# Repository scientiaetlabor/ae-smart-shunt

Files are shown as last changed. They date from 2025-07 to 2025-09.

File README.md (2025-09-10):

<h1 align="center">
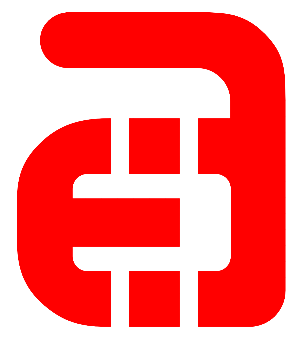
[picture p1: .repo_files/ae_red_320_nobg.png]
Ace's Electronics
    

  Ace's Electronics Pty Ltd  
  Smart Battery Shunt
</h1>

# Looking to get up and running?
- [Wiki - Quickstart Guide](../../wiki/Quickstart-Guide)

# Project Goals:
The overall goal of this project is to make a simple, robust and reliable Ssmart batery shunt to monitor voltage, current and power of a lithium battery, or battery system.

# Design goals:  
- Smallest form-factor possible while being able to handle large currents, upwards of 300A, without getting too hot
- Zero maintenance
- Allow the data to be accessed from an OLED gauge, via BLE or ESPNow

# Features
- **High-Precision Monitoring**: Measures battery voltage, current, and power, and calculates state-of-charge (SOC).
- **Persistent State**: Remembers battery capacity and calibration settings across power cycles.
- **ESP-NOW Broadcasting**: Transmits battery data wirelessly to other ESP devices.
- **Heartbeat LED**: A blinking LED provides a visual indication that the device is running.
- **Load Disconnect Control**: Includes an onboard MOSFET driver to disconnect the load in case of a fault.
- **Comprehensive Protection Suite**:
    - **Low-Voltage Disconnect**: Protects the battery from over-discharge. The device enters a low-power sleep mode, periodically waking to check if the battery has been recharged.
    - **Overcurrent Protection**: Disconnects the load if the current exceeds a configurable threshold.
    - **Short-Circuit Protection**: Uses the INA226's hardware alert pin for a fast-acting response to short circuits.
- **User-Configurable**: All protection parameters can be configured via the serial CLI.
- **In-Situ Calibration & Testing**: A guided CLI allows for accurate calibration and hardware verification without needing to re-flash the firmware.

# Commissioning
Before its first use, the smart shunt **must be calibrated**. The device will not be fully operational until this step is complete.
1.  Connect the device to a computer via USB.
2.  Open a serial monitor (e.g., the PlatformIO Serial Monitor) at **115200 baud**.
3.  Follow the on-screen prompts to run the calibration routines. You will be prompted to run the **Shunt Resistance Calibration (`r`)** first.
4.  Once calibration is complete, the device is ready for use.

# Serial Command-Line Interface (CLI)
The smart shunt is configured via a simple serial command-line interface. When connected, you can press a key followed by Enter to activate a command.

| Key | Command | Description |
|:---:|---|---|
| `c` | **Current Calibration** | Runs the guided multi-point current calibration routine. This maps the sensor's raw readings to true current values. |
| `r` | **Shunt Resistance Calibration** | Runs a routine to calculate the precise resistance of your shunt. **This must be run before first use.** |
| `p` | **Protection Settings** | Allows you to configure the thresholds for Low-Voltage Cutoff, Hysteresis, and Overcurrent Protection. |
| `l` | **Load Toggle** | Manually toggles the load disconnect MOSFET ON or OFF. Useful for testing the hardware circuit. |
| `a` | **Alert Toggle** | Toggles the hardware overcurrent alert ON or OFF. Useful for debugging. |
| `s` | **Status Display** | Displays the current protection settings, including the actual hardware alert threshold read from the INA226. |
| `d` | **Register Dump** | Prints the raw values of the INA226's key hardware registers for deep debugging. |

# v0.0.1
Version 0.0.1 has been prototyped. I will hand assemble some test boards and do some testing. ~ETA for completion is 10/8/25.

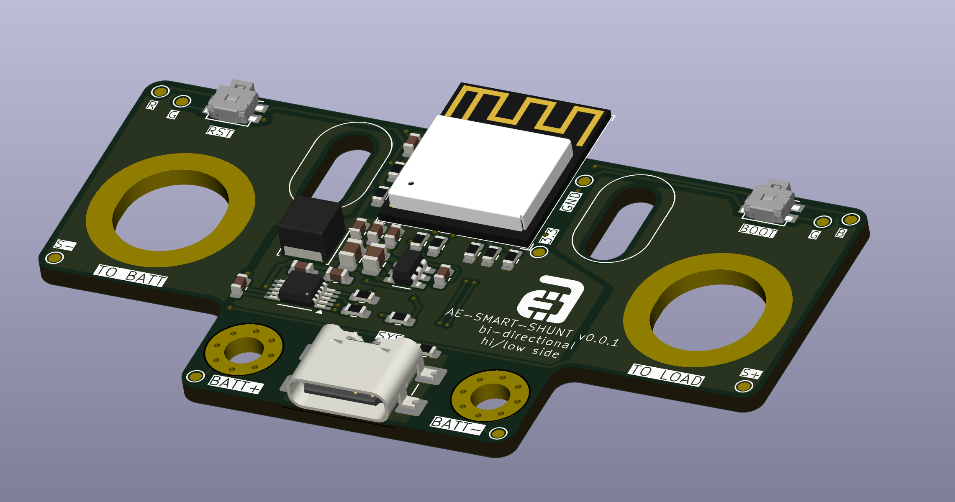
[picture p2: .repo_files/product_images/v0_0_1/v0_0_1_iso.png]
v0.0.1 PCB iso render

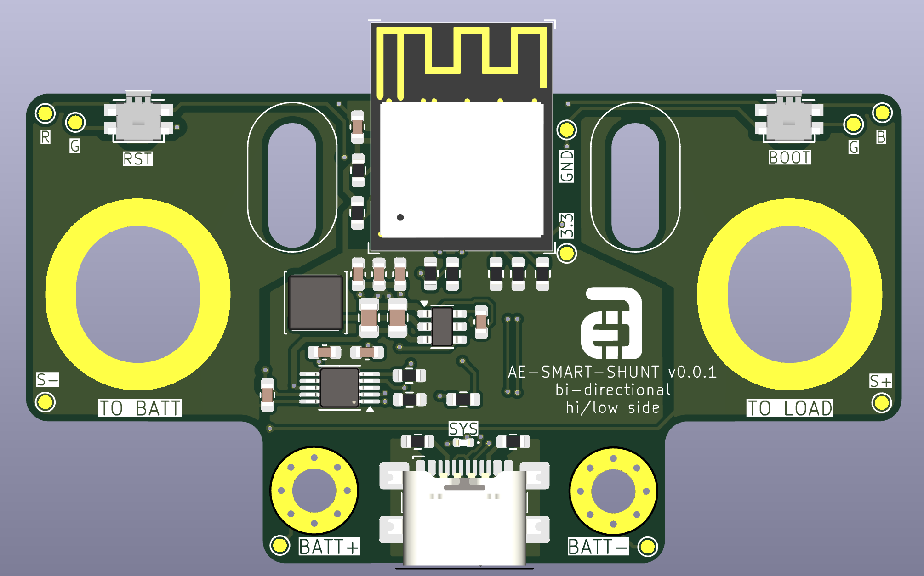
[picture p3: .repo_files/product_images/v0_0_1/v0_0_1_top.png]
v0.0.1 PCB top render

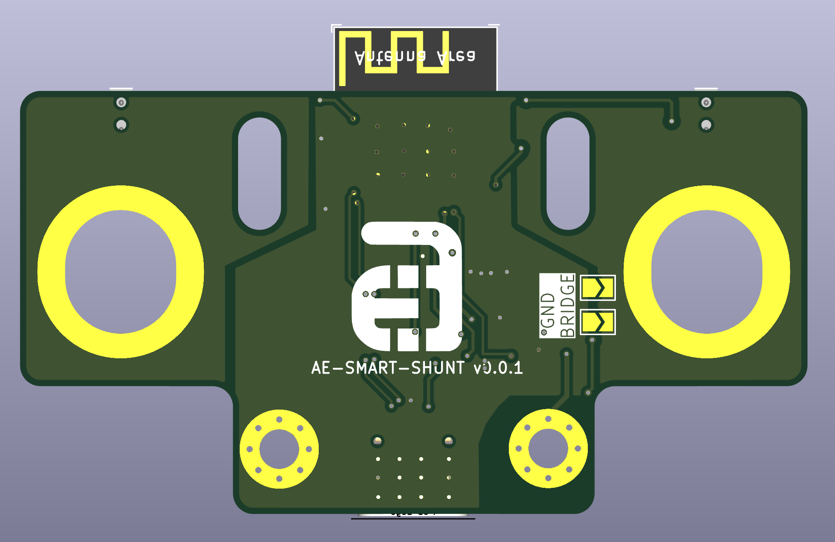
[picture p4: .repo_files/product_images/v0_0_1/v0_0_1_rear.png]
v0.0.1 PCB rear render

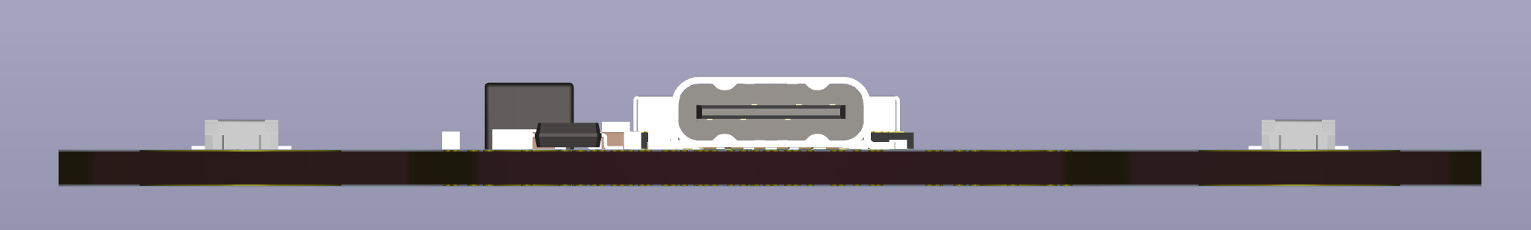
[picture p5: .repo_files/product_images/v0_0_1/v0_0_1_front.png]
v0.0.1 PCB front render


# Where to Buy:
TBA, but most likely will be vvailable to purchase in Australia or New Zealand via <a href="https://d1b959-f7.myshopify.com/">The AE Store</a>

## Support:
Contact me direct via ace<@>aceselectronics.com.au, just make it look like a normal email address. (hiding from the bots ;)

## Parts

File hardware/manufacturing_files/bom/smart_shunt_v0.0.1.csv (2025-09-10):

Reference | Value | Footprint | DNP | MFR | MFR# | lcsc
C1,C4,C6 | 10uF | Capacitor_SMD:C_0603_1608Metric,Capacitor_SMD:C_0805_2012Metric |  | Samsung Electro-Mechanics,muRata | CL10A106KP8NNNC,GRM21BR6YA106KE43L | C162422,C19702
C2,C5,C7,C8,C11 | 100nF | Capacitor_SMD:C_0603_1608Metric |  | YAGEO | CC0603KRX7R9BB104 | C14663
C3,C9,C10 | 22uF | Capacitor_SMD:C_0603_1608Metric |  | Samsung Electro-Mechanics | CL21A226MAQNNNE | C45783
C12 | 220nF | Capacitor_SMD:C_0805_2012Metric |  | Samsung Electro-Mechanics | CL21B224KBFNNNE | C5378
C13 | 220uF 50V | Capacitor_SMD:CP_Elec_8x10.5 |  | Honor Elec | VP1H221M0810 | C4054388
D1 | Green_LED | LED_SMD:LED_0402_1005Metric |  | Yongyu Photoelectric | SZYY0402YG | C434449
D5 | 1N5819WS | Diode_SMD:D_SOD-323 |  | JSMSEMI | 1N5819WS S4 | C2927280
J1 | SHUNT + | ShuntToPCB:MountingHole_17mm | DNP
J2 | SHUNT - | ShuntToPCB:MountingHole_17mm | DNP
J3 | VIn | MountingHole:MountingHole_3.2mm_M3_Pad_Via | DNP
J4 | USB_C_Receptacle_USB2.0 | Connector_USB:USB_C_Receptacle_GCT_USB4110 |  | SHOU HAN | TYPE-C 16P QTWT | C5187472
J5 | GND | MountingHole:MountingHole_3.2mm_M3_Pad_Via | DNP
J6 | Load Out | ShuntToPCB:MountingHole_17mm | DNP
L1 | 3.3uH | Inductor_SMD:L_APV_ANR4030 |  | Sunlord | SWPA4030S3R3MT | C15269
Q1,Q2 | CMSL008N06 | CMSL008N06:CMSL008N06 |  | Cmos | CMSL008N06 | C22364968
R1,R5,R6,R7,R8,R12 | 10k | Resistor_SMD:R_0603_1608Metric |  | UNI-ROYAL | 0603WAF1002T5E | C25804
R2,R3,R4,R9,R10 | 5.1k | Resistor_SMD:R_0603_1608Metric |  | UNI-ROYAL | 0603WAF5101T5E | C23186
R11,R13 | 33.2k | Resistor_SMD:R_0603_1608Metric |  | TyoHM | RMC060333.2K1%N | C325687
R14 | 180k | Resistor_SMD:R_0603_1608Metric |  | YAGEO | RC0603FR-07180KL | C123419
SW1,SW2 | SW_Push | Acea:ALPSALPINE-SKSCLBE010_C115361 |  | ALPSALPINE | SKSCLBE010 | C115361
U1 | ESP32-C3-MINI-1 | PCM_Espressif:ESP32-C3-MINI-1 |  | ESPRESSIF | ESP32-C3-MINI-1-H4 | C2934569
U2 | LM74502H-Q1 | Package_TO_SOT_SMD:SOT-23-8 |  | Texas Instruments | TI LM74502HQDDFRQ1 | C5219203
U4 | INA226 | Package_SO:VSSOP-10_3x3mm_P0.5mm |  | Texas Instruments | INA226AIDGSR | C49851
U5 | TPS562201 | Package_TO_SOT_SMD:SOT-23-6 |  | Texas Instruments | TPS562201DDCR | C90061

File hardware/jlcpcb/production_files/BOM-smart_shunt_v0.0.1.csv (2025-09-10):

Comment | Designator | Footprint | LCSC | Quantity
SW_Push | SW1,SW2 | ALPSALPINE-SKSCLBE010_C115361 | C115361 | 2
180k | R14 | R_0603_1608Metric | C123419 | 1
100nF | C11,C2,C5,C7,C8 | C_0603_1608Metric | C14663 | 5
3.3uH | L1 | L_APV_ANR4030 | C15269 | 1
10uF | C4,C6 | C_0805_2012Metric | C15850 | 2
10uF | C1 | C_0603_1608Metric | C19702 | 1
CMSL008N06 | Q1,Q2 | CMSL008N06 | C22364968 | 2
5.1k | R10,R2,R3,R4,R9 | R_0603_1608Metric | C23186 | 5
10k | R1,R12,R5,R6,R7,R8 | R_0603_1608Metric | C25804 | 6
ESP32-C3-MINI-1 | U1 | ESP32-C3-MINI-1 | C2838502 | 1
1N5819WS | D5 | D_SOD-323 | C2927280 | 1
33.2k | R11,R13 | R_0603_1608Metric | C325687 | 2
Green_LED | D1 | LED_0402_1005Metric | C401111 | 1
220uF 50V | C13 | CP_Elec_8x10.5 | C4054388 | 1
INA226 | U4 | VSSOP-10_3x3mm_P0.5mm | C49851 | 1
USB_C_Receptacle_USB2.0 | J4 | USB_C_Receptacle_GCT_USB4110 | C5187472 | 1
LM74502H-Q1 | U2 | SOT-23-8 | C5219203 | 1
220nF | C12 | C_0805_2012Metric | C5378 | 1
22uF | C10,C3,C9 | C_0603_1608Metric | C59461 | 3
TPS562201 | U5 | SOT-23-6 | C90061 | 1
SHUNT + |  | MountingHole_17mm |  | 0
GND |  | MountingHole_3.2mm_M3_Pad_Via |  | 0
SHUNT - |  | MountingHole_17mm |  | 0
VIn |  | MountingHole_3.2mm_M3_Pad_Via |  | 0
Load Out |  | MountingHole_17mm |  | 0

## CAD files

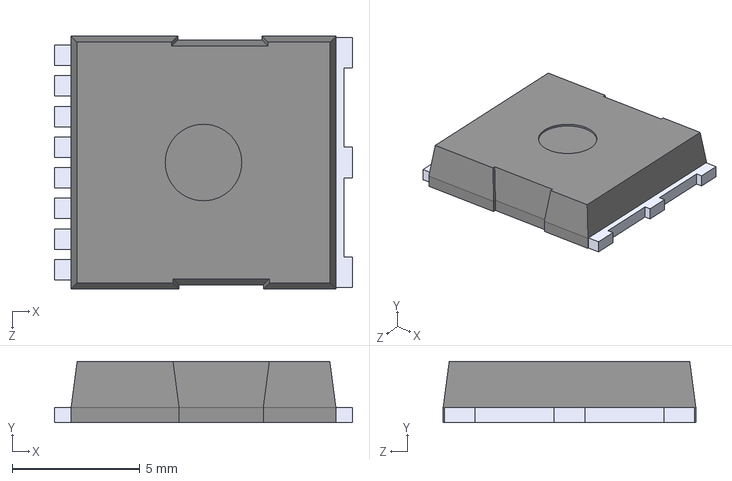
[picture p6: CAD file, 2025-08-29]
hardware/parts/CMSL008N06/CMSL008N06.step
11.7 x 2.40 x 9.90 mm

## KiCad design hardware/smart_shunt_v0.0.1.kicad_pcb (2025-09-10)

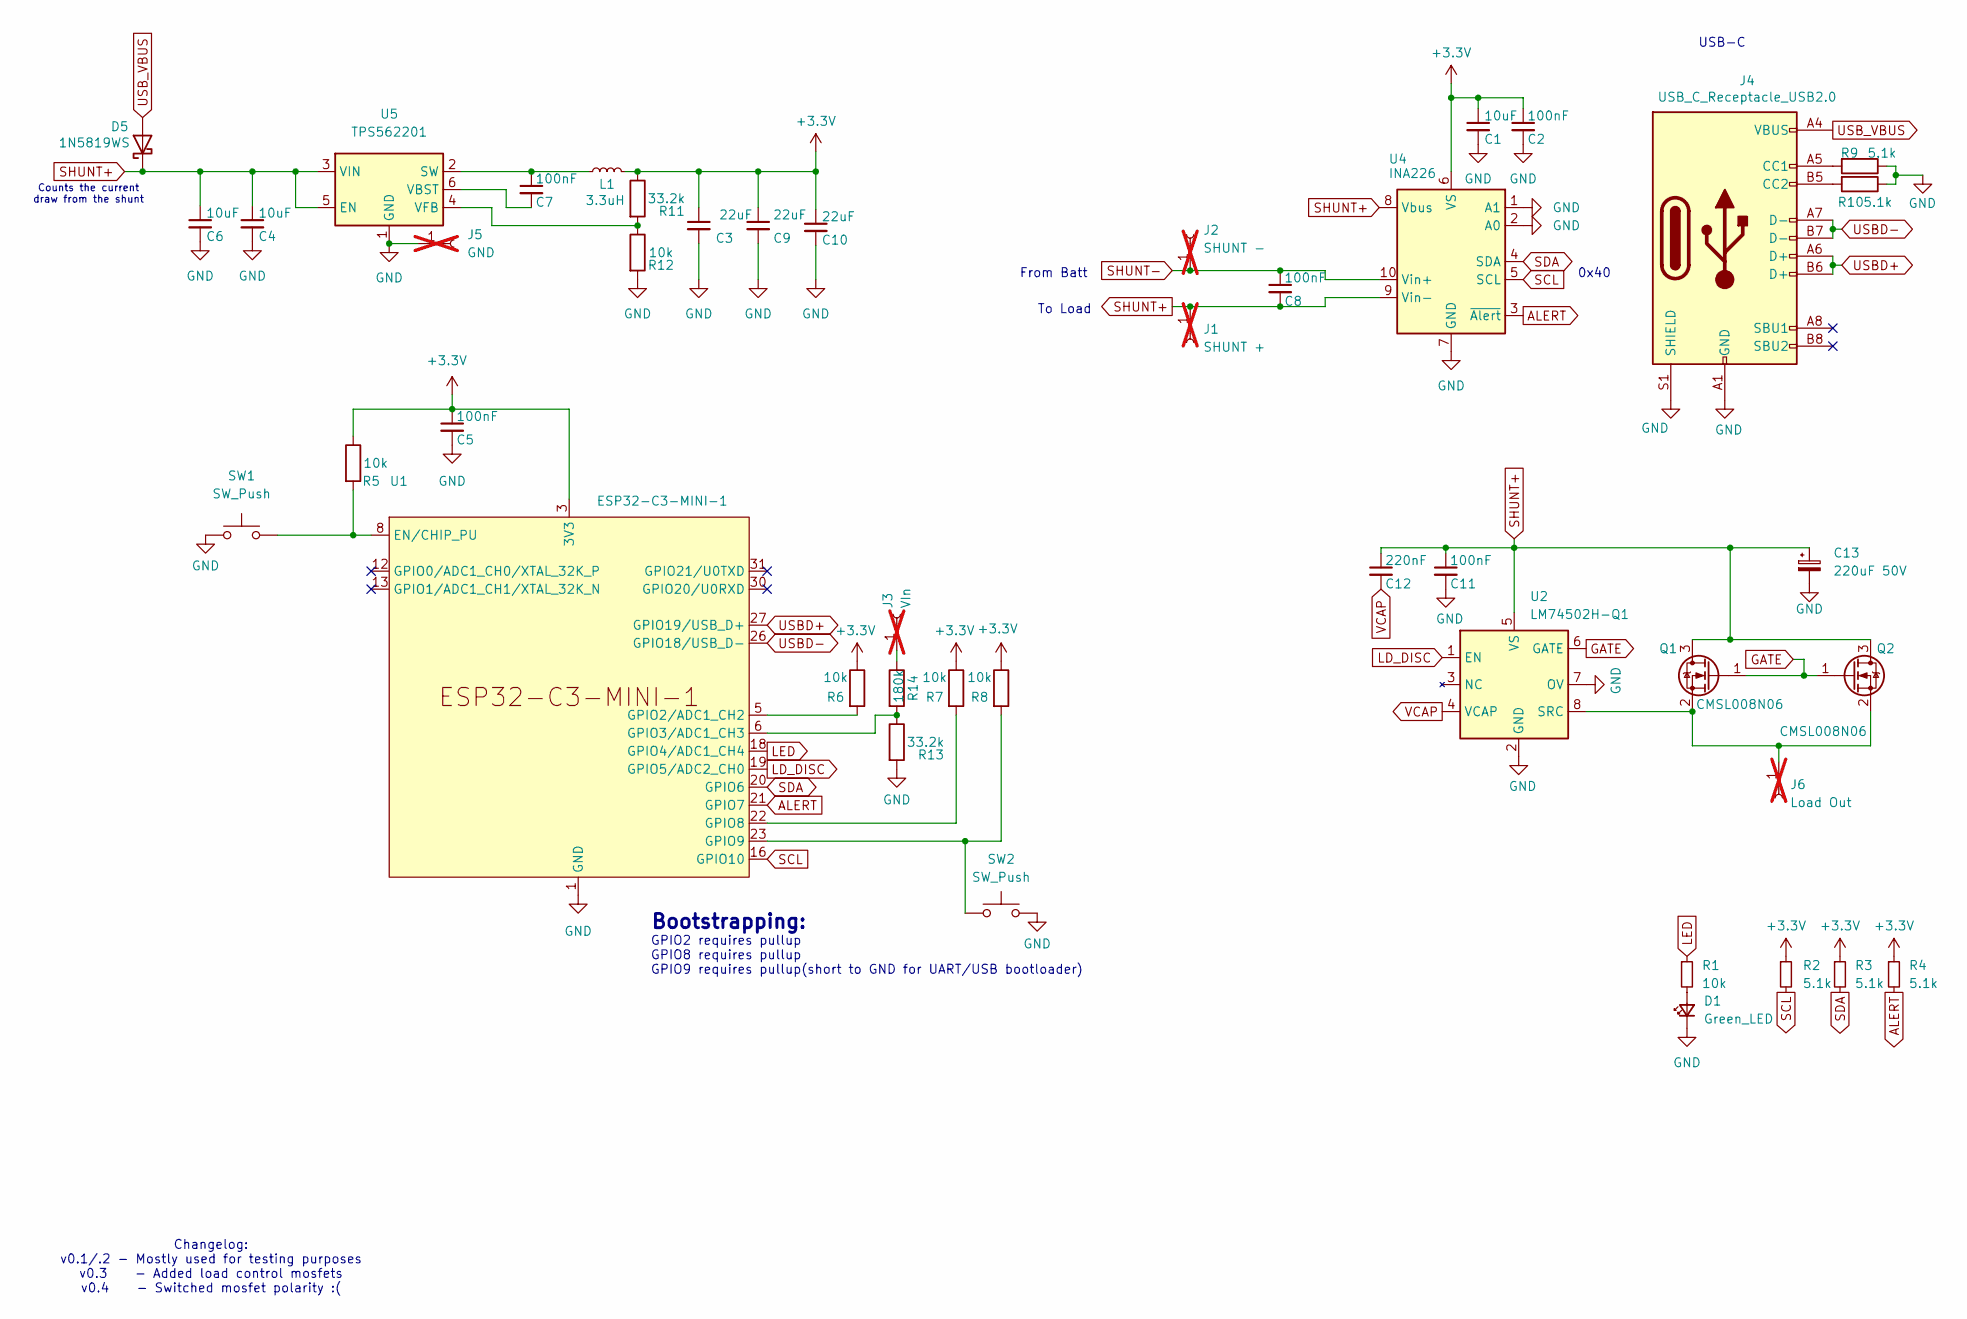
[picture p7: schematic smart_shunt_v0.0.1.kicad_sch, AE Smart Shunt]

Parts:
C1: 10uF; C_0603_1608Metric; MFR# CL10A106KP8NNNC; lcsc C19702
C2, C5, C7, C8, C11: 100nF; C_0603_1608Metric; MFR# CC0603KRX7R9BB104; lcsc C14663
C3, C9, C10: 22uF; C_0603_1608Metric; MFR# CL21A226MAQNNNE; lcsc C45783
C4, C6: 10uF; C_0805_2012Metric; MFR# GRM21BR6YA106KE43L; lcsc C162422
C12: 220nF; C_0805_2012Metric; MFR# CL21B224KBFNNNE; lcsc C5378
C13: 220uF 50V; CP_Elec_8x10.5; MFR# VP1H221M0810; lcsc C4054388
D1: Green_LED; LED_0402_1005Metric; MFR# SZYY0402YG; lcsc C434449
D5: 1N5819WS; D_SOD-323; MFR# 1N5819WS S4; lcsc C2927280
J1: SHUNT +; MountingHole_17mm; not fitted
J2: SHUNT -; MountingHole_17mm; not fitted
J3: VIn; MountingHole_3.2mm_M3_Pad_Via; not fitted
J4: USB_C_Receptacle_USB2.0; USB_C_Receptacle_GCT_USB4110; MFR# TYPE-C 16P QTWT; LCSC C5187472
J5: GND; MountingHole_3.2mm_M3_Pad_Via; not fitted
J6: Load Out; MountingHole_17mm; not fitted
L1: 3.3uH; L_APV_ANR4030; MFR# SWPA4030S3R3MT; lcsc C15269
Q1, Q2: CMSL008N06; MFR# CMSL008N06; lcsc C22364968
R1, R5, R6, R7, R8, R12: 10k; R_0603_1608Metric; MFR# 0603WAF1002T5E; lcsc C25804
R2, R3, R4, R9, R10: 5.1k; R_0603_1608Metric; MFR# 0603WAF5101T5E; lcsc C23186
R11, R13: 33.2k; R_0603_1608Metric; MFR# RMC060333.2K1%N; lcsc C325687
R14: 180k; R_0603_1608Metric; MFR# RC0603FR-07180KL; lcsc C123419
SW1, SW2: SW_Push; ALPSALPINE-SKSCLBE010_C115361; MFR# SKSCLBE010; lcsc C115361
U1: ESP32-C3-MINI-1; MFR# ESP32-C3-MINI-1-H4; lcsc C2934569
U2: LM74502H-Q1; SOT-23-8; MFR# TI LM74502HQDDFRQ1; lcsc C5219203
U4: INA226; VSSOP-10_3x3mm_P0.5mm; MFR# INA226AIDGSR; lcsc C49851
U5: TPS562201; SOT-23-6; MFR# TPS562201DDCR; lcsc C90061

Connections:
+3.3V: C1.1, C2.1, C3.1, C5.1, C9.1, C10.1, L1.2, R2.1, R3.1, R4.1, R5.1, R6.1, R7.1, R8.1, R11.1, U1.3 (3V3), U4.6 (VS)
ALERT: R4.2, U1.21 (GPIO7), U4.3 (~Alert)
GATE: Q1.1 (G), Q2.1 (G), U2.6 (GATE)
GND: C1.2, C2.2, C3.2, C4.2, C5.2, C6.2, C9.2, C10.2, C11.2, C13.2, D1.1 (K), J4.A1 (GND), J4.A12 (GND), J4.B1 (GND), J4.B12 (GND), J4.S1 (SHIELD), J5.1, R9.1, R10.1, R12.2, R13.2, SW1.2, SW2.2, U1.1 (GND), U1.2 (GND), U1.11 (GND), U1.14 (GND), U1.36 (GND), U1.37 (GND), U1.38 (GND), U1.39 (GND), U1.40 (GND), U1.41 (GND), U1.42 (GND), U1.43 (GND), U1.44 (GND), U1.45 (GND), U1.46 (GND), U1.47 (GND), U1.48 (GND), U1.49 (GND), U1.50 (GND), U1.51 (GND), U1.52 (GND), U1.53 (GND), U2.2 (GND), U2.7 (OV), U4.1 (A1), U4.2 (A0), U4.7 (GND), U5.1 (GND)
LD_DISC: U1.19 (GPIO5/ADC2_CH0), U2.1 (EN)
LED: R1.1, U1.18 (GPIO4/ADC1_CH4)
unnamed: D1.2 (A), R1.2
unnamed: J3.1, R14.1
unnamed: J4.A5 (CC1), R9.2
unnamed: J4.B5 (CC2), R10.2
unnamed: J6.1, Q1.2 (S), Q2.2 (S), U2.8 (SRC)
unnamed: R5.2, SW1.1, U1.8 (EN/CHIP_PU)
unnamed: R6.2, U1.5 (GPIO2/ADC1_CH2)
unnamed: R13.1, R14.2, U1.6 (GPIO3/ADC1_CH3)
unnamed: R7.2, U1.22 (GPIO8)
unnamed: R8.2, SW2.1, U1.23 (GPIO9)
unnamed: C7.1, L1.1, U5.2 (SW)
unnamed: C7.2, U5.6 (VBST)
unnamed: R11.2, R12.1, U5.4 (VFB)
SCL: R2.2, U1.16 (GPIO10), U4.5 (SCL)
SDA: R3.2, U1.20 (GPIO6), U4.4 (SDA)
SHUNT+: C4.1, C6.1, C8.2, C11.1, C12.1, C13.1, D5.1 (K), J1.1, Q1.3 (D), Q2.3 (D), U2.5 (VS), U4.8 (Vbus), U4.9 (Vin-), U5.3 (VIN), U5.5 (EN)
SHUNT-: C8.1, J2.1, U4.10 (Vin+)
USBD+: J4.A6 (D+), J4.B6 (D+), U1.27 (GPIO19/USB_D+)
USBD-: J4.A7 (D-), J4.B7 (D-), U1.26 (GPIO18/USB_D-)
USB_VBUS: D5.2 (A), J4.A4 (VBUS), J4.A9 (VBUS), J4.B4 (VBUS), J4.B9 (VBUS)
VCAP: C12.2, U2.4 (VCAP)

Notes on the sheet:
0x40
USB-C
From Batt
Counts the current draw from the shunt
Changelog: v0.1/.2 - Mostly used for testing purposes v0.3 - Added load control mosfets v0.4 - Switched mosfet polarity :(
To Load
Bootstrapping:
GPIO2 requires pullup GPIO8 requires pullup GPIO9 requires pullup(short to GND for UART/USB bootloader)

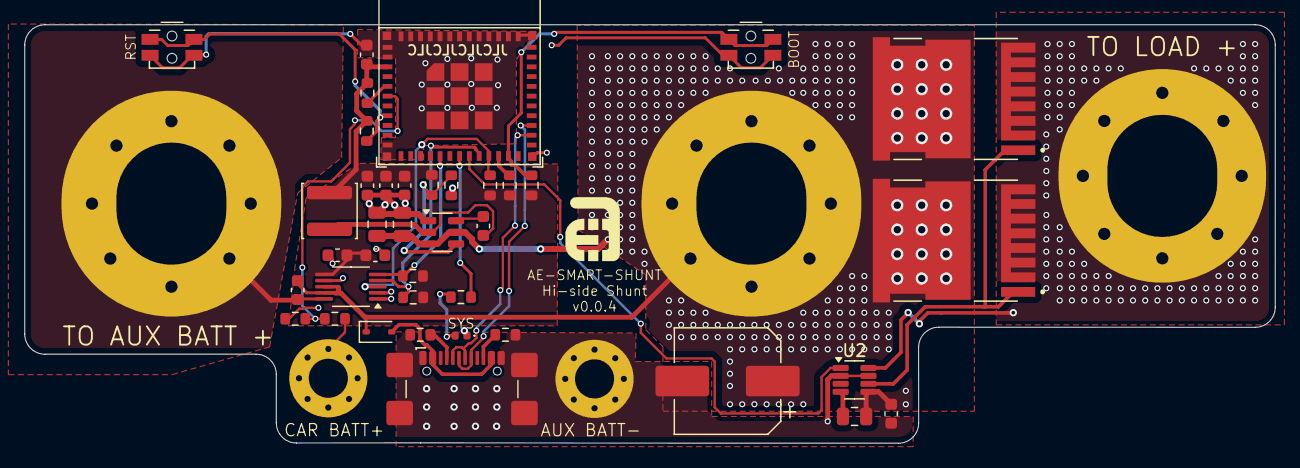
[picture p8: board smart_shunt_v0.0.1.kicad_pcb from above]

Board: 2 copper layers, 102.4 x 34.3 mm, 44 parts (0 on the bottom side), 27 nets.

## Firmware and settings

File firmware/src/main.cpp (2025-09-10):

#include <vector>
#include <Arduino.h>
#include <Preferences.h>
#include "shared_defs.h"
#include "ina226_adc.h"
#include "ble_handler.h"
#include "espnow_handler.h"
#include "passwords.h"
#include <esp_now.h>
#include <esp_err.h>

// WiFi and OTA
#include <WiFi.h>
#include <WiFiClientSecure.h>
#include <ota-github-cacerts.h>
#include <ota-github-defaults.h>
#define OTAGH_OWNER_NAME "Aces-Electronics"
#define OTAGH_REPO_NAME "ae-smart-shunt"
#include <OTA-Hub.hpp>

#define USE_ADC // if defined, use ADC, else, victron BLE
// #define USE_WIFI // if defined, conect to WIFI, else, don't

float batteryCapacity = 100.0f; // Default rated battery capacity in Ah (used for SOC calc)

uint8_t broadcastAddress[] = {0xFF, 0xFF, 0xFF, 0xFF, 0xFF, 0xFF};

// OTA update check interval (24 hours)
const unsigned long ota_check_interval = 24 * 60 * 60 * 1000;
unsigned long last_ota_check = 0;

// Main loop interval
const unsigned long loop_interval = 10000;
unsigned long last_loop_millis = 0;

// LED Heartbeat
unsigned long last_led_blink = 0;
const unsigned long led_blink_interval = 500; // ms

struct_message_ae_smart_shunt_1 ae_smart_shunt_struct;
// Initializing with a default shunt resistor value, which will be overwritten
// if a calibrated value is loaded from NVS.
INA226_ADC ina226_adc(I2C_ADDRESS, 0.000944464f, 100.00f);
ESPNowHandler espNowHandler(broadcastAddress); // ESP-NOW handler for sending data
WiFiClientSecure wifi_client;

void IRAM_ATTR alertISR() {
  ina226_adc.handleAlert();
}

bool handleOTA()
{
  // 1. Check for updates, by checking the latest release on GitHub
  OTA::UpdateObject details = OTA::isUpdateAvailable();

  if (OTA::NO_UPDATE == details.condition)
  {
    Serial.println("No new update available. Continuing...");
    return false;
  }
  else
  // 2. Perform the update (if there is one)
  {
    Serial.println("Update available, saving battery capacity...");
    Preferences preferences;
    preferences.begin("storage", false);
    float capacity = ina226_adc.getBatteryCapacity();
    preferences.putFloat("bat_cap", capacity);
    preferences.end();
    Serial.printf("Saved battery capacity: %f\n", capacity);

    if (OTA::performUpdate(&details) == OTA::SUCCESS)
    {
      // .. success! It'll restart by default, or you can do other things here...
      return true;
    }
  }
  return false;
}

void daily_ota_check()
{
  if (millis() - last_ota_check > ota_check_interval)
  {
    // Notify the user that we are checking for updates
    strncpy(ae_smart_shunt_struct.runFlatTime, "Checking for updates...", sizeof(ae_smart_shunt_struct.runFlatTime));
    espNowHandler.setAeSmartShuntStruct(ae_smart_shunt_struct);
    espNowHandler.sendMessageAeSmartShunt();
    delay(100); // Give a moment for the message to be sent

    // Stop ESP-NOW to allow WiFi to connect
    esp_now_deinit();

    // WiFi connection
    WiFi.begin(WIFI_SSID, WIFI_PASS);
    Serial.print("Connecting to WiFi for OTA check");
    while (WiFi.status() != WL_CONNECTED)
    {
      Serial.print(".");
      delay(500);
    }
    Serial.println("\nConnected to WiFi");

    bool updated = handleOTA();
    last_ota_check = millis();

    WiFi.disconnect(true);
    WiFi.mode(WIFI_OFF);
    Serial.println("WiFi disconnected");

    if (!updated)
    {
      // Re-initialize ESP-NOW
      if (!espNowHandler.begin())
      {
        Serial.println("ESP-NOW init failed after OTA check");
      }
    }
  }
}

// helper: read a trimmed line from Serial (blocks until newline)
static String SerialReadLineBlocking()
{
  String s;
  while (true)
  {
    while (Serial.available() == 0)
      delay(5);
    s = Serial.readStringUntil('\n');
    s.trim();
    if (s.length() > 0)
      return s;
    // allow empty Enter to be treated as empty string
    return s;
  }
}

// Helper: wait for enter or 'x' while optionally streaming debug raw vs calibrated values.
// Returns the user-entered line (possibly empty string if they just pressed Enter), or "x" if canceled.
static String waitForEnterOrXWithDebug(INA226_ADC &ina, bool debugMode)
{
  // Flush any existing chars
  while (Serial.available())
    Serial.read();

  unsigned long lastPrint = 0;
  const unsigned long printInterval = 300; // ms

  while (true)
  {
    if (Serial.available())
    {
      String line = Serial.readStringUntil('\n');
      line.trim();
      if (line.length() == 0)
      {
        // Enter pressed (empty line) - record step
        return String("");
      }
      else
      {
        // Could be 'x' or other input
        if (line.equalsIgnoreCase("x"))
          return String("x");
        // treat any non-empty as confirmation as well
        return line;
      }
    }

    // Periodically print debug readings if enabled
    unsigned long now = millis();
    if (debugMode && (now - lastPrint >= printInterval))
    {
      ina.readSensors();
      float raw = ina.getRawCurrent_mA();
      float cal = ina.getCurrent_mA();
      Serial.printf("RAW: %8.3f mA\tCAL: %8.3f mA   \r", raw, cal);
      lastPrint = now;
    }
    delay(20);
  }
}

// Renamed from runCalibrationMenu to be more specific
void runCurrentCalibrationMenu(INA226_ADC &ina)
{
  // First, check if the base shunt resistance has been calibrated.
  if (!ina.isConfigured()) {
    Serial.println(F("\n[ERROR] Base shunt resistance has not been calibrated."));
    Serial.println(F("Please run the 'r' (Shunt Resistance Calibration) command first."));
    return;
  }

  // Ensure load is enabled for calibration
  ina.setLoadConnected(true, MANUAL);
  Serial.println(F("Load enabled for calibration."));

  Serial.println(F("\n--- Current Calibration Menu ---"));
  Serial.println(F("Choose installed shunt rating (50-500 A in 50A steps) or 'x' to cancel:"));
  Serial.print(F("> "));

  String sel = SerialReadLineBlocking();
  if (sel.equalsIgnoreCase("x"))
  {
    Serial.println(F("Calibration canceled."));
    return;
  }

  int shuntA = sel.toInt();
  if (shuntA < 50 || shuntA > 500 || (shuntA % 50) != 0)
  {
    Serial.println(F("Invalid shunt rating. Aborting calibration."));
    return;
  }

  // Save the selected shunt as the active one
  Preferences prefs;
  prefs.begin(NVS_CAL_NAMESPACE, false);
  prefs.putUShort(NVS_KEY_ACTIVE_SHUNT, shuntA);
  prefs.end();
  Serial.printf("Set %dA as active shunt.\n", shuntA);

  // Show existing linear + table calibration (if any)
  float g0, o0;
  bool hadLinear = ina.loadCalibration(shuntA);
  ina.getCalibration(g0, o0);

  size_t storedCount = 0;
  bool hasTableStored = ina.hasStoredCalibrationTable(shuntA, storedCount);
  bool hasTableRAM = ina.loadCalibrationTable(shuntA);

  if (hadLinear)
    Serial.printf("Loaded LINEAR calibration for %dA: gain=%.9f offset_mA=%.3f\n", shuntA, g0, o0);
  else
    Serial.printf("No stored LINEAR calibration for %dA. Using defaults gain=%.9f offset_mA=%.3f\n", shuntA, g0, o0);

  if (hasTableStored)
  {
    Serial.printf("Found TABLE calibration for %dA with %u points. Loaded into RAM.\n", shuntA, (unsigned)storedCount);
  }
  else
  {
    Serial.printf("No TABLE calibration stored for %dA.\n", shuntA);
  }

  // Ask if user wants live debug streaming while waiting for each step
  Serial.println(F("Enable live debug stream (raw vs calibrated) while waiting to record each step? (y/N)"));
  Serial.print(F("> "));
  String dbgAns = SerialReadLineBlocking();
  bool debugMode = dbgAns.equalsIgnoreCase("y") || dbgAns.equalsIgnoreCase("yes");

  // build measurement percentages
  std::vector<float> perc;
  perc.push_back(0.0f);    // 0%
  perc.push_back(0.02f);   // 2%  (1A on 50A shunt)
  perc.push_back(0.04f);   // 4%  (2A on 50A shunt)
  perc.push_back(0.1f);    // 10% (5A on 50A shunt)
  perc.push_back(0.2f);    // 20% (10A on 50A shunt)
  perc.push_back(0.4f);    // 40% (20A on 50A shunt)
  perc.push_back(0.6f);    // 60% (30A on 50A shunt)
  perc.push_back(0.8f);    // 80% (40A on 50A shunt)
  perc.push_back(1.0f);    // 100%(50A on 50A shunt)

  std::vector<float> measured_mA;
  std::vector<float> true_mA;

  size_t last_measured_idx = 0;

  for (size_t i = 0; i < perc.size(); ++i)
  {
    float p = perc[i];
    float trueA = shuntA * p;
    float true_milli = trueA * 1000.0f;

    // --- Measure points up to and including 50% ---
    if (p <= 0.5f) {
        if (p == 0.0f) {
        Serial.printf("\nStep %u of %u: Target = %.3f A (Zero Load).\nDisconnect all loads from the shunt, then press Enter to record. Enter 'x' to cancel.\n",
                        (unsigned)(i + 1), (unsigned)perc.size(), trueA);
        } else {
        Serial.printf("\nStep %u of %u: Target = %.3f A (%.2f%% of %dA).\nSet test jig to the target current, then press Enter to record. Enter 'x' to cancel and accept measured so far.\n",
                        (unsigned)(i + 1), (unsigned)perc.size(), trueA, p * 100.0f, shuntA);
        }

        Serial.print("> ");
        String line = waitForEnterOrXWithDebug(ina, debugMode);
        if (line.equalsIgnoreCase("x")) {
            Serial.println("User canceled early; accepting tests recorded so far.");
            break;
        }

        const int samples = 8;
        float sumRaw = 0.0f;
        for (int s = 0; s < samples; ++s) {
            ina.readSensors();
            sumRaw += ina.getRawCurrent_mA();
            delay(120);
        }
        float avgRaw = sumRaw / (float)samples;
        Serial.printf("Recorded avg raw reading: %.3f mA  (expected true: %.3f mA)\n", avgRaw, true_milli);
        measured_mA.push_back(avgRaw);
        true_mA.push_back(true_milli);
        last_measured_idx = i;
    }
  }

  // --- Extrapolate for points > 50% ---
  if (last_measured_idx > 0 && last_measured_idx < perc.size() - 1) {
    Serial.println("\nExtrapolating remaining points > 50%...");

    // Get the last two measured points to establish a linear trend
    float raw1 = measured_mA[last_measured_idx - 1];
    float true1 = true_mA[last_measured_idx - 1];
    float raw2 = measured_mA[last_measured_idx];
    float true2 = true_mA[last_measured_idx];

    // Calculate the slope (gain) of the last segment
    float slope = (raw2 - raw1) / (true2 - true1);

    for (size_t i = last_measured_idx + 1; i < perc.size(); ++i) {
        float p = perc[i];
        float trueA = shuntA * p;
        float true_milli = trueA * 1000.0f;

        // Extrapolate the raw value
        float extrapolated_raw = raw2 + slope * (true_milli - true2);

        Serial.printf("Extrapolated Point: raw=%.3f mA -> true=%.3f mA (%.2f%%)\n", extrapolated_raw, true_milli, p * 100.0f);
        measured_mA.push_back(extrapolated_raw);
        true_mA.push_back(true_milli);
    }
  }

  size_t N = measured_mA.size();
  if (N == 0)
  {
    Serial.println("No measurements taken; leaving calibration unchanged.");
    return;
  }

  // -------- Build & save calibration TABLE (piecewise linear) --------
  std::vector<CalPoint> points;
  points.reserve(N);
  for (size_t i = 0; i < N; ++i)
  {
    points.push_back({measured_mA[i], true_mA[i]});
    Serial.printf("Point %u: raw=%.3f mA -> true=%.3f mA\n", (unsigned)i, measured_mA[i], true_mA[i]);
  }

  // Wipe any existing calibration for this shunt before saving new one
  ina.clearCalibrationTable(shuntA);

  // Save table (this also sorts/dedups internally and loads into RAM)
  if (ina.saveCalibrationTable(shuntA, points))
  {
    Serial.println("\nCalibration complete (TABLE).");
    Serial.printf("Saved %u calibration points for %dA shunt.\n", (unsigned)points.size(), shuntA);
  }
  else
  {
    Serial.println("\nCalibration failed: no points saved.");
    return; // Can't run tests if calibration failed
  }

  Serial.println("These values are persisted and will be applied to subsequent current readings.");

  // --- Guided Tests ---
  Serial.println(F("\n--- Guided Hardware Tests ---"));
  Serial.println(F("Would you like to run guided tests to verify hardware functionality? (y/N)"));
  Serial.print(F("> "));
  String testAns = SerialReadLineBlocking();
  if (!testAns.equalsIgnoreCase("y")) {
    Serial.println("Skipping hardware tests.");
    return;
  }

  // Test 1: Load Switch Test
  Serial.println(F("\n--- Test 1: Load Switch ---"));
  Serial.println(F("This test will verify the load disconnect MOSFET."));
  Serial.println(F("Please apply a constant 1A load, then press Enter."));
  Serial.print(F("> "));
  waitForEnterOrXWithDebug(ina, false);

  delay(500);
  ina.readSensors();
  float current_before = ina.getCurrent_mA();
  Serial.printf("Current before disconnect: %.3f mA\n", current_before);

  Serial.println("Disconnecting load...");
  ina.setLoadConnected(false, MANUAL);
  delay(500); // Wait for load to disconnect and reading to settle

  ina.readSensors();
  float current_after = ina.getCurrent_mA();
  float no_load_current = measured_mA[0]; // First point was zero-load
  Serial.printf("Current after disconnect: %.3f mA (expected ~%.3f mA)\n", current_after, no_load_current);

  if (abs(current_after - no_load_current) < 50.0f) { // Allow 50mA tolerance
    Serial.println(F("SUCCESS: Load switch appears to be working."));
  } else {
    Serial.println(F("FAILURE: Current did not drop to no-load value. Check MOSFET wiring."));
  }

  // Reconnect load for next test
  Serial.println("Reconnecting load...");
  ina.setLoadConnected(true, NONE);
  delay(500);

  // Test 2: Overcurrent Alert Test
  Serial.println(F("\n--- Test 2: Overcurrent Alert ---"));
  Serial.println(F("This test will verify the INA226 alert functionality."));

  float test_current = 0.5f; // 500mA
  Serial.printf("The alert threshold will be temporarily set to %.3f A.\n", test_current);
  Serial.println(F("Please ensure your load is set to 0A, then press Enter."));
  Serial.print(F("> "));
  waitForEnterOrXWithDebug(ina, false);

  ina.setTempOvercurrentAlert(test_current);

  Serial.println(F("Now, slowly increase the load. The load should disconnect when you exceed the test threshold."));
  Serial.println(F("The test will wait for 15 seconds..."));

  bool alert_fired = false;
  unsigned long test_start = millis();
  while(millis() - test_start < 15000) { // 15s timeout
      if (ina.isAlertTriggered()) {
          ina.processAlert();
          alert_fired = true;
          break;
      }
      delay(50);
  }

  if (alert_fired) {
    Serial.println(F("SUCCESS: Overcurrent alert triggered and load was disconnected."));
  } else {
    Serial.println(F("FAILURE: Alert did not trigger within 15 seconds. Check INA226 wiring."));
  }

  // Restore original alert configuration
  ina.restoreOvercurrentAlert();
  // Ensure load is connected for normal operation
  ina.setLoadConnected(true, NONE);
}

void printShunt(const struct_message_ae_smart_shunt_1 *p) {
  if (!p) return;

  Serial.printf(
    "=== Local Shunt ===\n"
    "Message ID     : %d\n"
    "Data Changed   : %s\n"
    "Voltage        : %.2f V\n"
    "Current        : %.2f A\n"
    "Power          : %.2f W\n"
    "SOC            : %.1f %%\n"
    "Capacity       : %.2f Ah\n"
    "State          : %d\n"
    "Run Flat Time  : %s\n"
    "===================\n",
    p->messageID,
    p->dataChanged ? "true" : "false",
    p->batteryVoltage,
    p->batteryCurrent,
    p->batteryPower,
    p->batterySOC * 100.0f,
    p->batteryCapacity,
    p->batteryState,
    p->runFlatTime
  );
}
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
void loop()
{
  // LED Heartbeat
  if (millis() - last_led_blink > led_blink_interval) {
    digitalWrite(LED_PIN, !digitalRead(LED_PIN));
    last_led_blink = millis();
  }

  if (ina226_adc.isAlertTriggered()) {
    ina226_adc.processAlert();
  }

  daily_ota_check();

  // Check serial for calibration command
  if (Serial.available())
  {
    String s = Serial.readStringUntil('\n');
    s.trim();
    if (s.equalsIgnoreCase("c"))
    {
      // run the current calibration menu
      runCurrentCalibrationMenu(ina226_adc);
    }
    else if (s.equalsIgnoreCase("r"))
    {
      // run the new shunt resistance calibration
      runShuntResistanceCalibration(ina226_adc);
    }
    else if (s.equalsIgnoreCase("p"))
    {
      // run the protection configuration menu
      runProtectionConfigMenu(ina226_adc);
    }
    else if (s.equalsIgnoreCase("l"))
    {
      // toggle load connection
      if (ina226_adc.isLoadConnected()) {
          ina226_adc.setLoadConnected(false, MANUAL);
          Serial.println("Load manually toggled OFF");
      } else {
          ina226_adc.setLoadConnected(true, NONE);
          Serial.println("Load manually toggled ON");
      }
    }
    else if (s.equalsIgnoreCase("e"))
    {
      // export calibration data
      runExportCalibrationMenu(ina226_adc);
    }
    else if (s.equalsIgnoreCase("a"))
    {
      // toggle hardware alert
      ina226_adc.toggleHardwareAlerts();
      if (ina226_adc.areHardwareAlertsDisabled()) {
          Serial.println("Hardware alerts DISABLED.");
      } else {
          Serial.println("Hardware alerts ENABLED.");
      }
    }
    else if (s.equalsIgnoreCase("s"))
    {
      // print protection status
      Serial.println(F("\n--- Protection Status ---"));
      int alertPinState = digitalRead(INA_ALERT_PIN);
      Serial.print(F("Alert Pin State      : "));
      Serial.print(alertPinState == HIGH ? "INACTIVE (HIGH)" : "ACTIVE (LOW)");
      Serial.println();
      Serial.print(F("Hardware Alerts      : "));
      Serial.println(ina226_adc.areHardwareAlertsDisabled() ? "DISABLED" : "ENABLED");
      Serial.print(F("Configured Threshold : "));
      Serial.print(ina226_adc.getOvercurrentThreshold());
      Serial.println(F(" A"));
      Serial.print(F("Actual HW Threshold  : "));
      Serial.print(ina226_adc.getHardwareAlertThreshold_A());
      Serial.println(F(" A"));
      Serial.print(F("Low Voltage Cutoff   : "));
      Serial.print(ina226_adc.getLowVoltageCutoff());
      Serial.println(F(" V"));
      Serial.print(F("Hysteresis           : "));
      Serial.print(ina226_adc.getHysteresis());
      Serial.println(F(" V"));
      Serial.println(F("-------------------------"));
    }
    else if (s.equalsIgnoreCase("d"))
    {
      // dump INA226 registers
      ina226_adc.dumpRegisters();
    }
    // else ignore — keep running
  }

  if (millis() - last_loop_millis > loop_interval)
  {
#ifdef USE_ADC
    if (ina226_adc.isConfigured()) {
      ina226_adc.checkAndHandleProtection();
    }

    ina226_adc.readSensors();

    // Populate struct fields
    ae_smart_shunt_struct.messageID = 11;
    ae_smart_shunt_struct.dataChanged = true;

    ae_smart_shunt_struct.batteryVoltage = ina226_adc.getBusVoltage_V();
    ae_smart_shunt_struct.batteryCurrent = ina226_adc.getCurrent_mA() / 1000.0f;
    ae_smart_shunt_struct.batteryPower = ina226_adc.getPower_mW() / 1000.0f;

    ae_smart_shunt_struct.batteryState = 0; // 0 = Normal, 1 = Warning, 2 = Critical

    // Update remaining capacity in the INA226 helper (expects current in A)
    ina226_adc.updateBatteryCapacity(ina226_adc.getCurrent_mA() / 1000.0f);

    // Get remaining Ah from INA helper
    float remainingAh = ina226_adc.getBatteryCapacity();
    ae_smart_shunt_struct.batteryCapacity = remainingAh; // remaining capacity in Ah
    // batteryCapacity global holds the rated capacity in Ah for SOC calculation
    if (batteryCapacity > 0.0f)
    {
      ae_smart_shunt_struct.batterySOC = remainingAh / batteryCapacity; // fraction 0..1
    }
    else
    {
      ae_smart_shunt_struct.batterySOC = 0.0f;
    }

    if (ina226_adc.isOverflow())
    {
      Serial.println("Overflow! Choose higher current range");
      ae_smart_shunt_struct.batteryState = 3; // overflow indicator
    }

    // Calculate and print run-flat time with warning threshold
    bool warning = false;
    float currentA = ina226_adc.getCurrent_mA() / 1000.0f; // convert mA to A
    float warningThresholdHours = 10.0f;

    String avgRunFlatTimeStr = ina226_adc.getAveragedRunFlatTime(currentA, warningThresholdHours, warning);

    strncpy(ae_smart_shunt_struct.runFlatTime, avgRunFlatTimeStr.c_str(), sizeof(ae_smart_shunt_struct.runFlatTime));
    ae_smart_shunt_struct.runFlatTime[sizeof(ae_smart_shunt_struct.runFlatTime) - 1] = '\0'; // ensure null termination

#else
    // Code to use victron BLE
    bleHandler.startScan(scanTime);

    // Provide safe defaults so struct is still valid
    ae_smart_shunt_struct.messageID = 0;
    ae_smart_shunt_struct.dataChanged = false;
    ae_smart_shunt_struct.batteryVoltage = 0.0f;
    ae_smart_shunt_struct.batteryCurrent = 0.0f;
    ae_smart_shunt_struct.batteryPower = 0.0f;
    ae_smart_shunt_struct.batteryCapacity = 0.0f;
    ae_smart_shunt_struct.batterySOC = 0.0f;
    ae_smart_shunt_struct.batteryState = 0;
    strncpy(ae_smart_shunt_struct.runFlatTime, "N/A", sizeof(ae_smart_shunt_struct.runFlatTime));
#endif

    // Send the data via ESP-NOW if configured
    if (ina226_adc.isConfigured()) {
      espNowHandler.setAeSmartShuntStruct(ae_smart_shunt_struct);
      espNowHandler.sendMessageAeSmartShunt();
    }

#ifdef USE_ADC
    printShunt(&ae_smart_shunt_struct);
    if (ina226_adc.isOverflow())
    {
      Serial.println("Warning: Overflow condition!");
    }
#endif

    Serial.println();
    last_loop_millis = millis();
  }
}

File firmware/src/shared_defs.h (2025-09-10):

#ifndef SHARED_DEFS_H
#define SHARED_DEFS_H

#include <stdint.h>

// Pin definitions
#define LOAD_SWITCH_PIN 5
#define INA_ALERT_PIN 7
#define LED_PIN 4

// NVS keys
#define NVS_CAL_NAMESPACE "ina_cal"
#define NVS_KEY_ACTIVE_SHUNT "active_shunt"
#define NVS_PROTECTION_NAMESPACE "protection"
#define NVS_KEY_LOW_VOLTAGE_CUTOFF "lv_cutoff"
#define NVS_KEY_HYSTERESIS "hysteresis"
#define NVS_KEY_OVERCURRENT "oc_thresh"

#define I2C_ADDRESS 0x40
const int scanTime = 5;

extern uint8_t broadcastAddress[6];

typedef struct {
  uint16_t vendorID;
  uint8_t beaconType;
  uint8_t unknownData1[3];
  uint8_t victronRecordType;
  uint16_t nonceDataCounter;
  uint8_t encryptKeyMatch;
  uint8_t victronEncryptedData[21];
  uint8_t nullPad;
} __attribute__((packed)) victronManufacturerData;

typedef struct {
   uint8_t deviceState;
   uint8_t outputState;
   uint8_t errorCode;
   uint16_t alarmReason;
   uint16_t warningReason;
   uint16_t inputVoltage;
   uint16_t outputVoltage;
   uint32_t offReason;
   uint8_t  unused[32];
} __attribute__((packed)) victronPanelData;

typedef struct struct_message_voltage0 {
  int messageID;
  bool dataChanged;
  float frontMainBatt1V;
  float frontAuxBatt1V;
  float rearMainBatt1V;
  float rearAuxBatt1V;
  float frontMainBatt1I;
  float frontAuxBatt1I;
  float rearMainBatt1I;
  float rearAuxBatt1I; 
} struct_message_voltage0;

typedef struct struct_message_ae_smart_shunt_1 {
  int messageID;
  bool dataChanged;
  float batteryVoltage;
  float batteryCurrent;
  float batteryPower;
  float batterySOC;
  float batteryCapacity;
  int batteryState;
  char runFlatTime[40];
} __attribute__((packed)) struct_message_ae_smart_shunt_1;

#endif // SHARED_DEFS_H

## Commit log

2025-07-20 v0.0.1 off to JLCPCB
    [BOM-smart_shunt_v0.0.1.csv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]
2025-08-15 Updated RFT and calibration
2025-08-16 feat: Add comprehensive test suite for firmware
    This change introduces a comprehensive test suite for the firmware.
    It adds a native test environment to allow for unit testing on a host machine.
    This required creating mocks for various Arduino and ESP-IDF libraries.
    The test suite covers:
    - Current, voltage, and power calculations.
    - Battery capacity and run-flat time calculations.
    - Calibration persistence.
    - ESP-NOW message handling.
    - Main application logic.
    A workaround was used to get the build system to link the source files
    with the tests, which involves including the .cpp files directly in the
    main test file. This is not ideal but ensures the tests can be run in
    the current environ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
    [espnow_handler.cpp, test_main.cpp]
2025-08-16 fix: C++11 warnings and run-flat time warning logic
    - Add -std=c++11 to build flags to fix C++11 warnings.
    - Correct the logic in calculateRunFlatTimeFormatted to only trigger the low-time warning when discharging.
    [ina226_adc.cpp, test_main.cpp]
2025-08-17 feat: Add CI workflow for OTA releases
    This commit updates the CI workflow to automatically build the firmware and create a GitHub release when a new version tag is pushed.
    This is a necessary step for the OTA update functionality to work, as the device needs to download the `firmware.bin` from a GitHub release.
2025-08-17 fix: Use correct header for OTA library
    This commit corrects the include statement for the OTA library.
    The `README.md` of the library was outdated. The correct header is `OTA-Hub.hpp`, not `OTA-Hub-diy.hpp`.
    [main.cpp]
2025-08-17 Adding resistance calibration
2025-08-29 v0.0.2 update, before FETs
    [BOM-smart_shunt_v0.0.1.csv, CMSL008N06.step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]
2025-08-31 v0.0.3 off to JLCPCB
    [BOM-smart_shunt_v0.0.1.csv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]
2025-09-09 feat: Implement load protection and sleep features
    This commit introduces several new features to the smart shunt firmware:
    - **Load Disconnect Control:** The firmware can now control a load-disconnect MOSFET connected to GPIO5. The load is disconnected if the battery voltage or current go outside of user-defined ranges.
    - **Short-Circuit/Overcurrent Protection:** The INA226 alert pin, connected to GPIO7, is used to trigger an interrupt in case of a short circuit or overcurrent event. This provides a fast-acting protection mechanism that immediately disconnects the load.
    - **Low-Voltage Cutoff with Deep Sleep:** When the battery voltage drops below a configurable threshold, the load is di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
    [ina226_adc.cpp, main.cpp, shared_defs.h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]
2025-09-09 fix: Prevent deep sleep on USB power
    This commit fixes an issue where the device would enter deep sleep when powered from USB for setup, due to the low voltage protection being triggered by a low voltage reading when no battery is connected.
    The `checkAndHandleProtection` function is modified to bypass the low-voltage protection logic if the measured voltage is below 5.25V.
    A new unit test is added to verify this behavior.
    [ina226_adc.cpp, test_main.cpp]
2025-09-09 fix: Refactor alert handling and fix tests
    This commit fixes several issues with the protection features:
    - **ISR Watchdog Timeout:** The INA226 alert handling has been refactored to prevent a watchdog timeout. The Interrupt Service Routine (ISR) now only sets a volatile flag. The main loop checks this flag and processes the alert, which includes disconnecting the load and clearing the INA226 alert status. This moves all slow operations (Serial prints, I2C communication) out of the ISR.
    - **Test Logic:** The unit test for the alert disconnect (`test_alert_disconnect`) has been corrected to accurately reflect the new ISR-and-main-loop interaction. It now simulates the ISR setting the flag,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
    [ina226_adc.cpp, main.cpp, test_main.cpp]
2025-09-09 fix: Prevent alert spam when load is disconnected
    This commit fixes an issue where the INA226 alert would continuously
    trigger and flood the serial log if the alert condition persisted after
    the load was disconnected.
    The `processAlert` function is modified to only take action (print a
    message and disconnect the load) if the load is currently connected. If
    an alert is received while the load is already disconnected, the alert
    is simply cleared on the INA226 chip and the software flag is reset,
    preventing repeated messages.
    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
    [ina226_adc.cpp, test_main.cpp]
2025-09-09 fix: Clear spurious startup alerts
    This commit fixes a race condition where the INA226 alert pin could
    become active during power-on before the ESP32's interrupt handler was
    attached, causing an immediate, spurious alert trigger at startup.
    A new public method, `clearAlerts()`, has been added to the `INA226_ADC`
    class. This method is called in `setup()` immediately before the
    interrupt is attached to ensure that any pending alert flags on the
    INA226 chip are cleared. This guarantees that the system starts in a
    known-good state.
    [ina226_adc.cpp, main.cpp]
2025-09-09 feat: Add commissioning check on startup
    This commit introduces a commissioning check to ensure the device is not
    used before it has been configured.
    The device is now considered "configured" only after the shunt
    resistance has been successfully calibrated and saved to NVS at least
    once.
    If the device boots up in an unconfigured state, it will:
    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
2025-09-09 fix: Resolve compilation error from name conflict
    This commit fixes a compilation error caused by a member variable and a
    member function both being named `isConfigured`.
    The member variable has been renamed to `m_isConfigured` to resolve the
    conflict. All uses of the variable have been updated to the new name.
    [ina226_adc.cpp]
2025-09-09 fix: Improve calibration live stream UI
    This commit improves the user experience of the live debug stream during
    the calibration process.
    The `Serial.printf` call that prints the live data now uses a carriage
    return (`\r`) instead of a newline (`\n`). This causes the output to
    overwrite itself on a single line, preventing the calibration step
    instructions from scrolling off the screen.
    The format specifier was also updated to provide fixed-width output,
    ensuring consistent alignment.
    [main.cpp]
2025-09-09 fix: Add robust check for device configuration
    This commit fixes a bug where the "device not configured" reminder was
    not being displayed on first boot.
    The `loadShuntResistance` function has been made more robust. It now
    explicitly checks for the existence of the `ina_cal` NVS namespace and
    the `cal_ohms` key before considering the device configured.
    This ensures that on a fresh device, the `isConfigured` flag is
    correctly set to false, which in turn triggers the warning message in
    the CLI and disables the load output and ESP-NOW transmissions until
    the device is calibrated.
    [ina226_adc.cpp]
2025-09-09 feat: Improve current calibration accuracy
    This commit improves the accuracy of the current calibration routine by
    implementing two user-requested changes:
    1. **Self-Consumption Compensation**: A new initial step has been added
    to the calibration process to measure the device's own current draw
    with no external loads connected. This measured self-consumption is
    then used as an offset and subtracted from all subsequent raw
    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
2025-09-09 refactor: Improve calibration by using zero-load point
    This commit refactors the current calibration routine to improve its
    accuracy and robustness, addressing user feedback.
    The previous method of measuring a separate self-consumption offset and
    subtracting it from readings was flawed. The new implementation follows
    a more standard multi-point calibration procedure:
    1. The calibration process now starts with a true "zero external load"
    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
2025-09-09 feat: Add heartbeat LED, load toggle, and interactive tests
    This commit introduces several new features to improve device feedback
    and testing capabilities:
    1. **Heartbeat LED**: The onboard LED on GPIO4 now blinks every 500ms
    to provide a constant visual indication that the device firmware is
    running.
    2. **Manual Load Toggle**: A new 'l' command has been added to the CLI
    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
2025-09-09 feat: Use whole-number targets in calibration routine
    This commit improves the usability of the current calibration routine
    by adjusting the set points to use whole numbers.
    The underlying percentage vector has been modified so that for common
    shunt ratings (e.g., 50A, 100A), the resulting target currents
    are simple whole numbers (e.g., 1A, 2A, 5A), making the process
    easier for the user to follow.
2025-09-09 refactor: Configure INA226 range based on active shunt
    This commit refactors the INA226 initialization to address a design
    flaw that was causing significant measurement inaccuracies at low
    currents.
    Previously, the INA226's internal registers were configured using a
    hardcoded maximum current (100A), which is not optimal for all shunt
    ratings.
    The new implementation introduces the concept of an "active shunt
    rating", which is saved to NVS during calibration. On every boot, the
    firmware now:
    1. Loads the active shunt rating from NVS.
    2. Uses this rating to correctly configure the INA226's measurement
    range, optimizing its resolution and accuracy for the specific
    hardware in use.
    3.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
    [ina226_adc.cpp, main.cpp, shared_defs.h]
2025-09-09 feat: Implement comprehensive shunt protection and usability features
    This commit introduces a wide range of new features and improvements to
    the smart shunt firmware, turning it into a much more robust and
    user-friendly device.
    Major features include:
    1. **Load Protection & Disconnect**:
    * The firmware now actively controls a load disconnect MOSFET.
    * The load is disconnected if the battery voltage drops below a
    configurable threshold (Low-Voltage Disconnect).
    * The load is disconnected if the current exceeds a configurable
    threshold (Overcurrent Protection).
    2. **Hardware Short-Circuit Alert**:
    * Uses the INA226's hardware alert pin for fast-acting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
    [ina226_adc.cpp, main.cpp, test_main.cpp]
2025-09-09 chore: Add debugging for MOSFET control
    This commit adds verbose serial printing to the `setLoadConnected`
    function to help diagnose an issue where the load disconnect toggle is
    not working as expected.
    This is a temporary change to gather more information from the hardware
    and will be reverted before the final fix is committed.
    [ina226_adc.cpp]
2025-09-09 docs: Update README with new features and usage
    This commit significantly updates the main README.md file to document
    all the new features and functionality that have been added to the
    firmware.
    The new sections include:
    - **Features**: A high-level overview of the smart shunt's
    capabilities, including the new protection suite.
    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
2025-09-09 feat: Add calibration export and extrapolation
    This commit introduces two major improvements to the calibration
    process based on user feedback:
    1. **Calibration Data Export**: A new 'e' command has been added to the
    CLI. This command allows the user to export the stored multi-point
    calibration data for a given shunt rating. The data is printed to
    the serial console formatted as a C++ vector, which can be easily
    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
2025-09-10 Feature/toggle hardware alert (#7)
    * feat: Add keyboard toggle for hardware overcurrent alert
    Introduces a keyboard command ('a') to toggle the INA226 hardware overcurrent alert on and off.
    This allows the user to disable the immediate load disconnect feature for testing and debugging purposes, as requested.
    The implementation includes:
    - A new flag `m_hardwareAlertsDisabled` in the `INA226_ADC` class.
    - A `toggleHardwareAlerts()` method to flip the state.
    - Modified `configureAlert()` to enable/disable the alert on the INA226 chip.
    - A guard in `processAlert()` to prevent action when alerts are disabled.
    - The 'a' key command in the main loop to trigger the toggle and provide user feedba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
    [ina226_adc.cpp, main.cpp]
2025-09-10 Fixing reversed MOSFETs
    [BOM-smart_shunt_v0.0.1.csv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]
2025-09-10 Fixing ADC trace - Thanks Vincent!
    [CPL-smart_shunt_v0.0.1.csv, smart_shunt_v0.0.1-CuBottom.gbr, smart_shunt_v0.0.1-CuTop.gbr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]
2025-09-10 Sent files to assembler
    Removed values from from front fab layer
    Added missing reference designators from front fab layer
    Added manufacturer and manufacturer part numbers to BOM
    Replaced 180K and 220nF parts in BOM
    [smart_shunt_v0.0.1-B_Cu.gbr, smart_shunt_v0.0.1-B_Mask.gbr, smart_shunt_v0.0.1-B_Paste.gbr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]
